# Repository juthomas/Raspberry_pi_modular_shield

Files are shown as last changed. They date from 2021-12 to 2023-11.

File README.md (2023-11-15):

# Raspberry Pi hat for modular synthesizer input

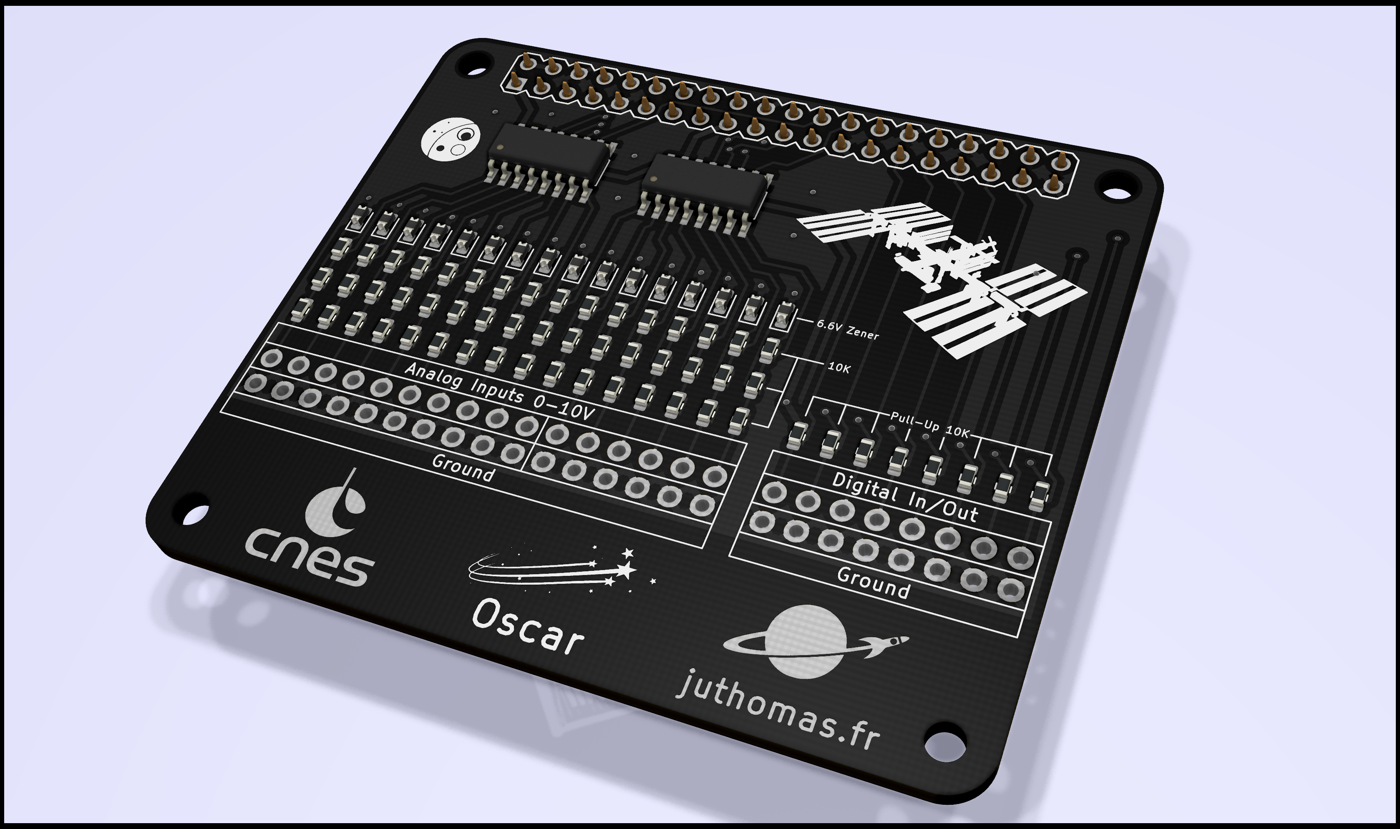
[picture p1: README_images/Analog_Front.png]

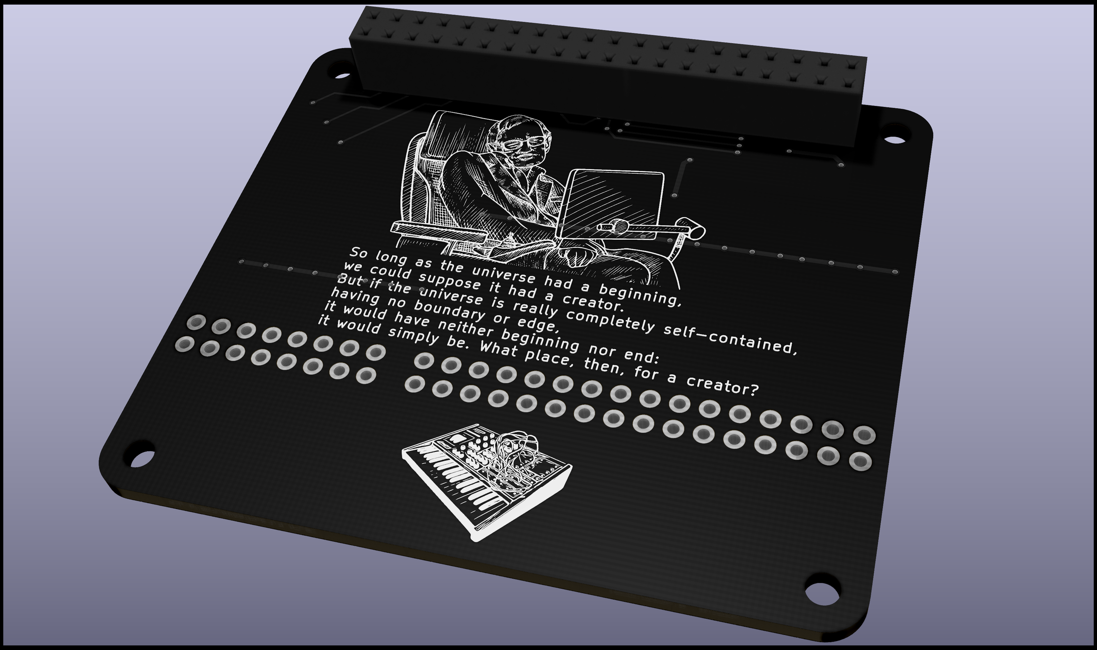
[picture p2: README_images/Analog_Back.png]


## Schematics

- [Link to pdf](https://github.com/juthomas/Raspberry_pi_modular_shield/blob/master/Schematics%20PDF/Modular_Shield.pdf)

## Bill Of Materials

- [Link to IBOM](https://juthomas.github.io/Raspberry_pi_modular_shield/)

## Components

- [10K Resistors](https://www.lcsc.com/product-detail/Chip-Resistor-Surface-Mount_UNI-ROYAL-Uniroyal-Elec-0603WAF1002T5E_C25804.html) C25804

- [Zener Diodes](https://www.lcsc.com/product-detail/Zener-Diodes_onsemi-SZMM5Z6V8T1G_C894569.html) C894569

- [MCP3008](https://www.lcsc.com/product-detail/Analog-To-Digital-Converters-ADCs_Microchip-Tech-MCP3008-I-SL_C1520159.html) C1520159

## Install dependency for C coding

[spidev-lib](https://github.com/juthomas/spidev-lib)

dont forget to add the `-lspidev-lib` flag when compiling

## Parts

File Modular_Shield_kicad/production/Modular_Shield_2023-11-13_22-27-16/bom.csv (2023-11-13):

Designator | Footprint | Quantity | Value | LCSC Part #
D1, D10, D11, D12, D13, D14, D15, D16, D2, D3, D4, D5, D6, D7, D8, D9 | 0603 | 16 | D_Zener 6.6V | C894569
R1, R10, R11, R12, R13, R14, R15, R16, R17, R18, R19, R2, R20, R21, R22, R23, R24, R25, R26, R27, R28, R29, R3, R30, R31, R32, R33, R34, R35, R36, R37, R38, R39, R4, R40, R41, R42, R43, R44, R45, R46, R47, R48, R49, R5, R50, R51, R52, R53, R54, R55, R56, R6, R7, R8, R9 | 0603 | 56 | 10K | C25804
U1, U3 | MCP3008 SOIC16 | 2 | MCP3008 | C1520159

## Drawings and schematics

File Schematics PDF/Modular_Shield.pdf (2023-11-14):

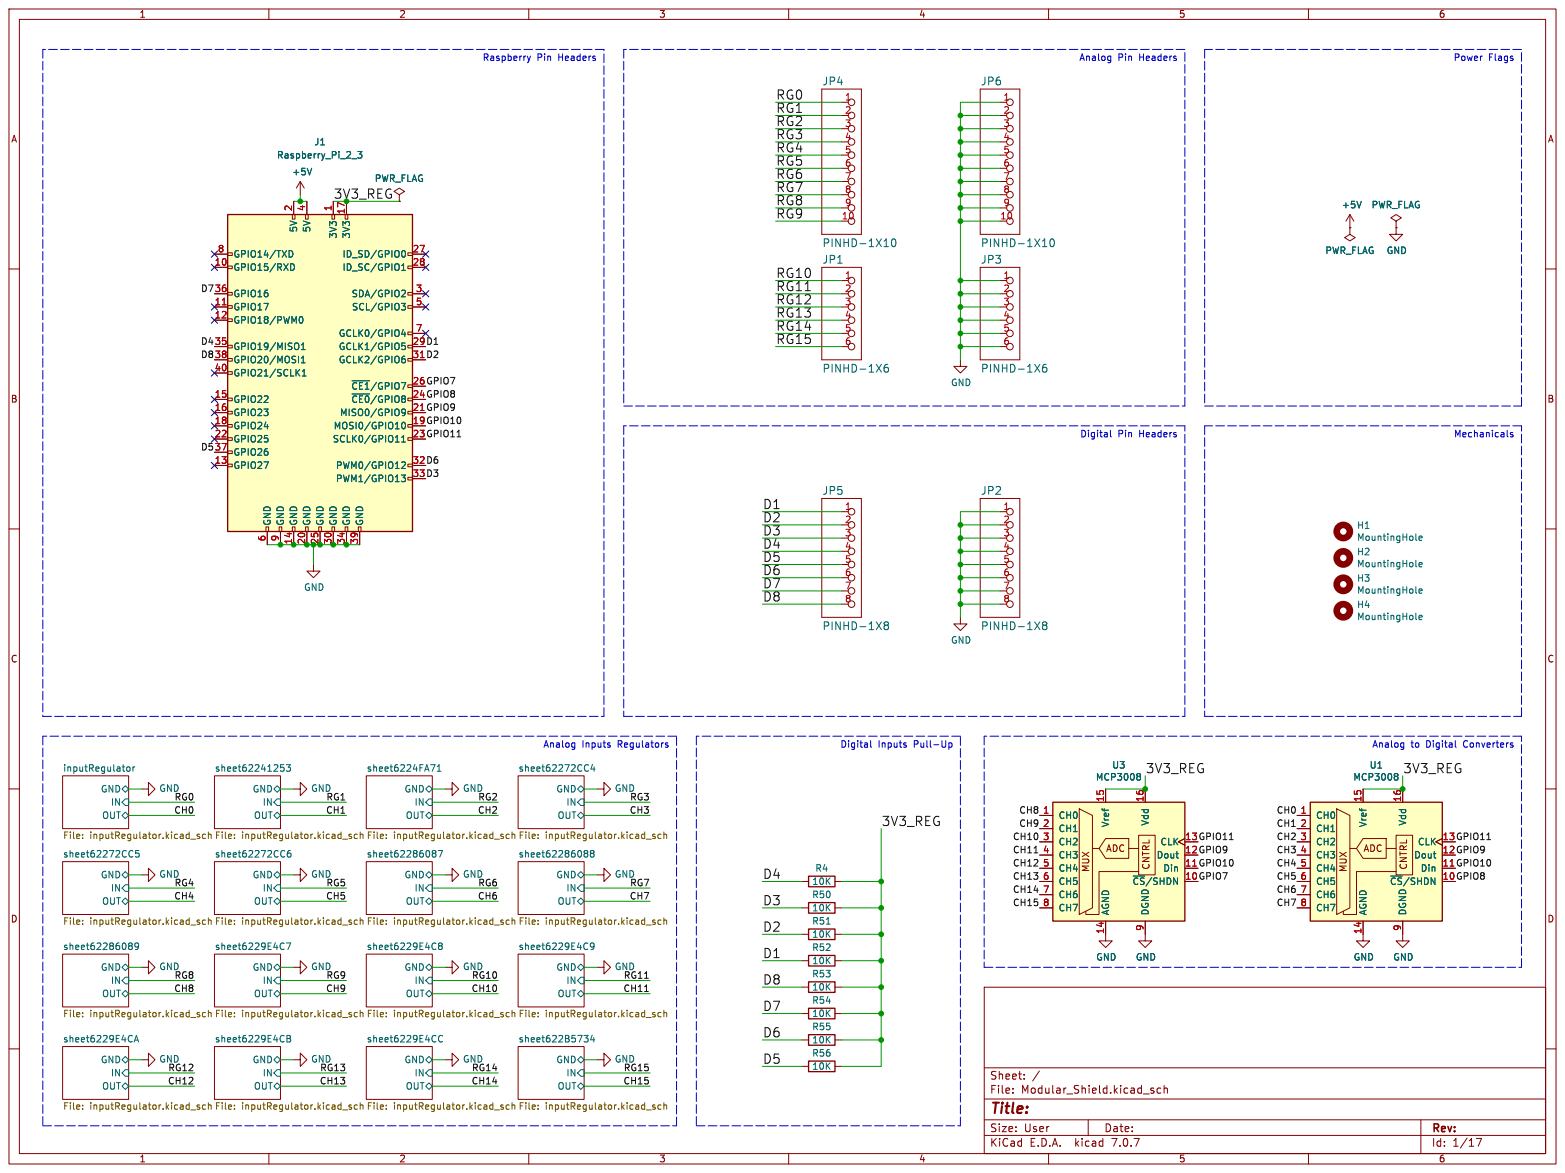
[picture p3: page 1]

9 U3 MCP3008 H1 MountingHole H3 MountingHole H4 MountingHole H2 MountingHole

Digital Inputs Pull-Up

9 U1 MCP3008 GND GND GND GND

9 GND GND GND GND

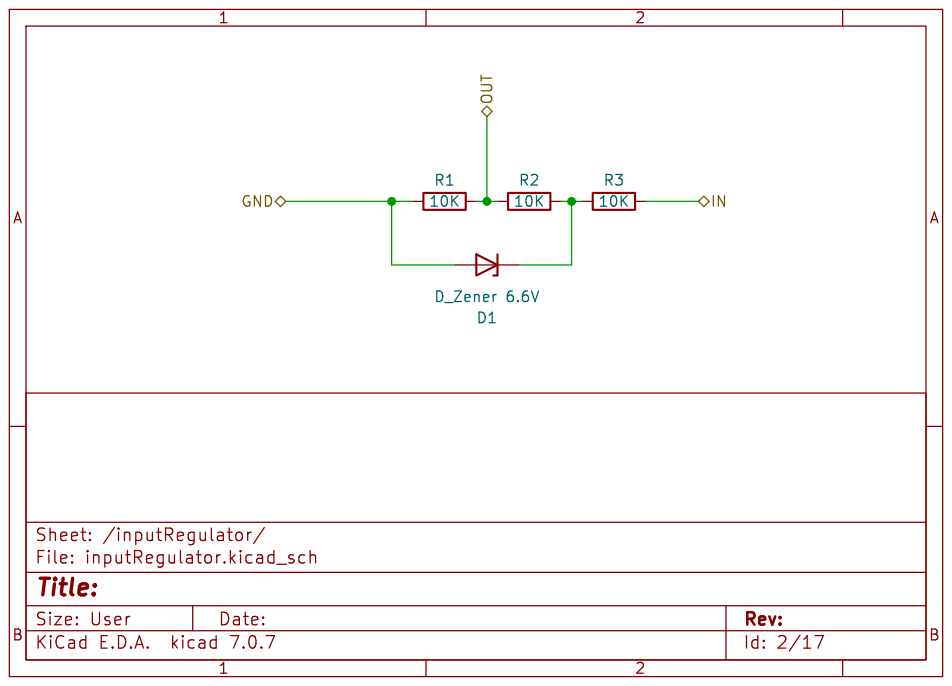
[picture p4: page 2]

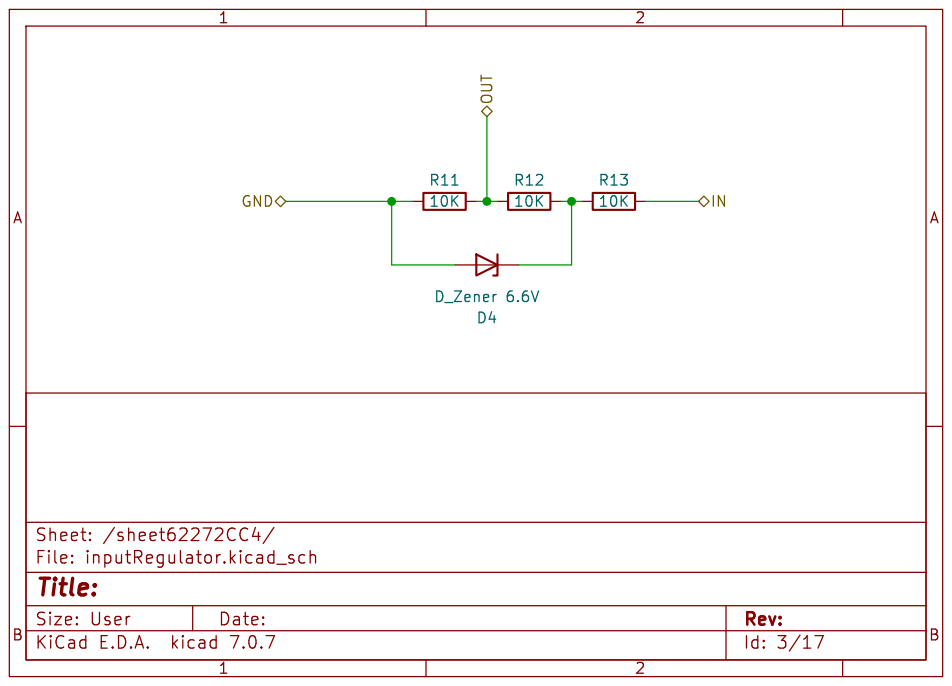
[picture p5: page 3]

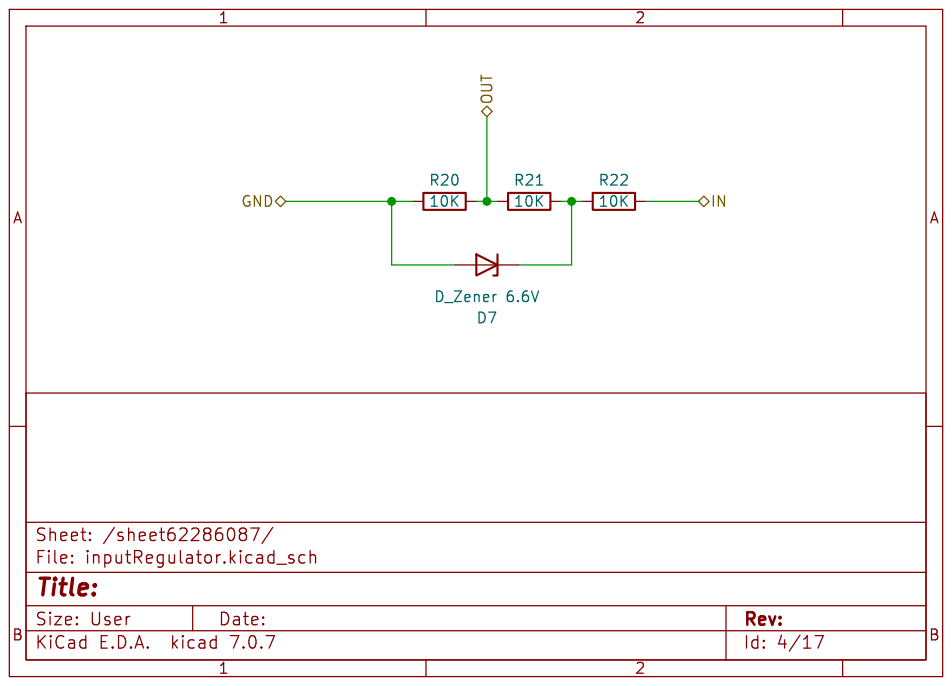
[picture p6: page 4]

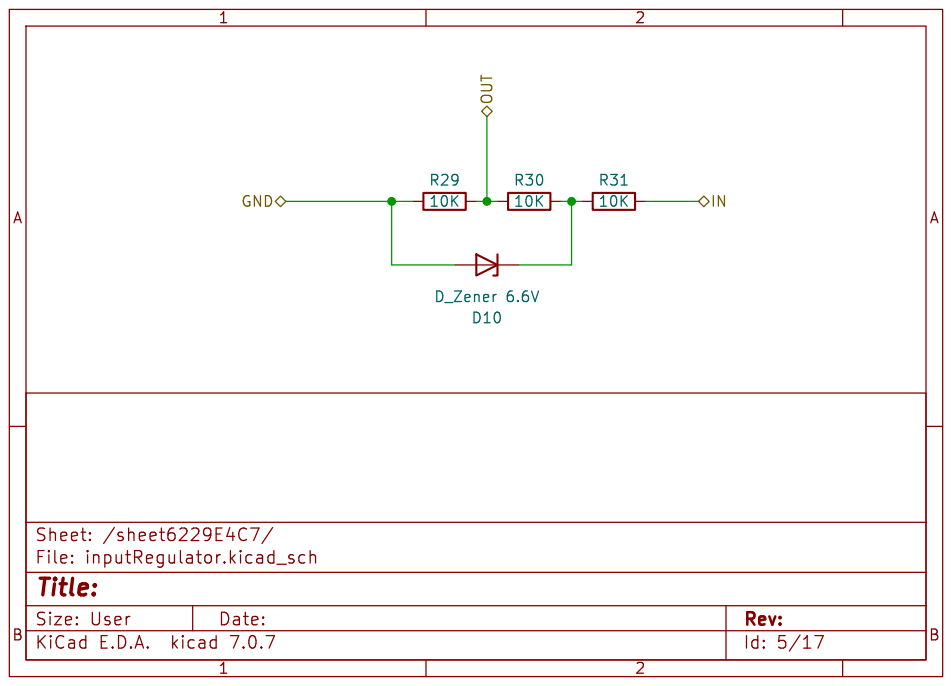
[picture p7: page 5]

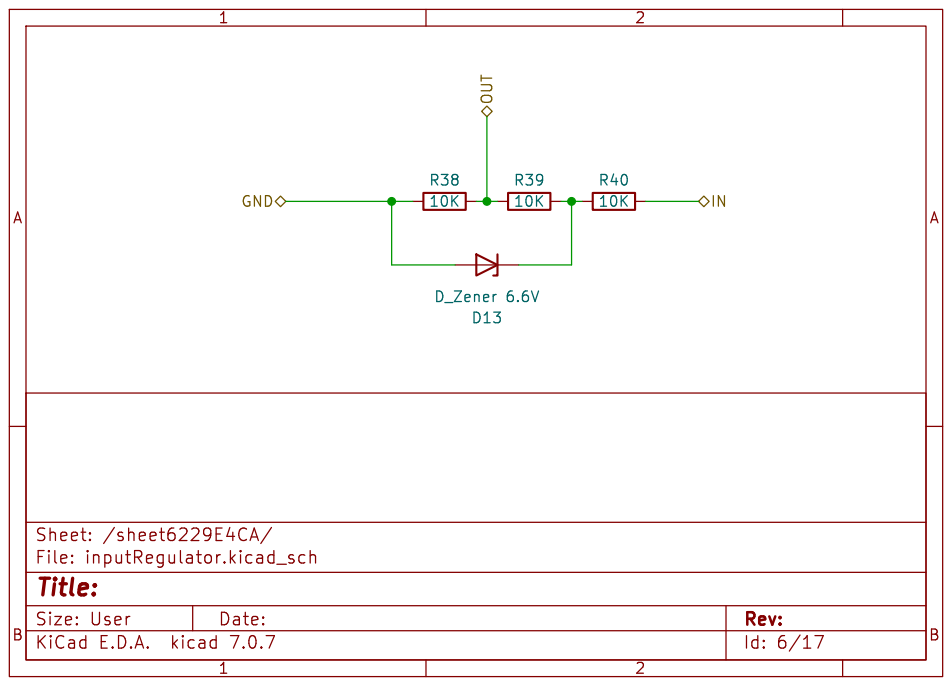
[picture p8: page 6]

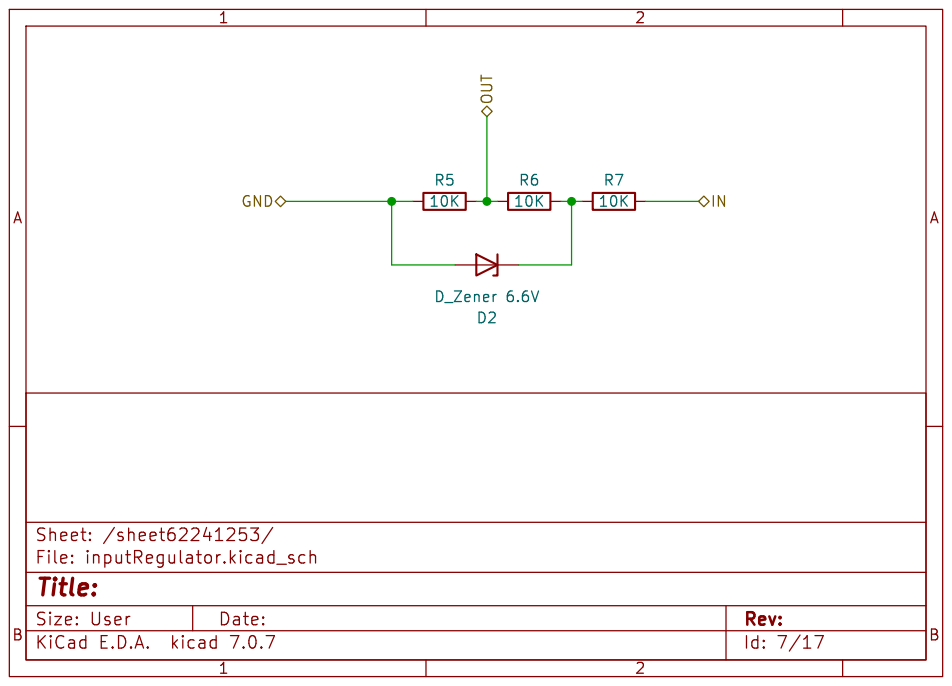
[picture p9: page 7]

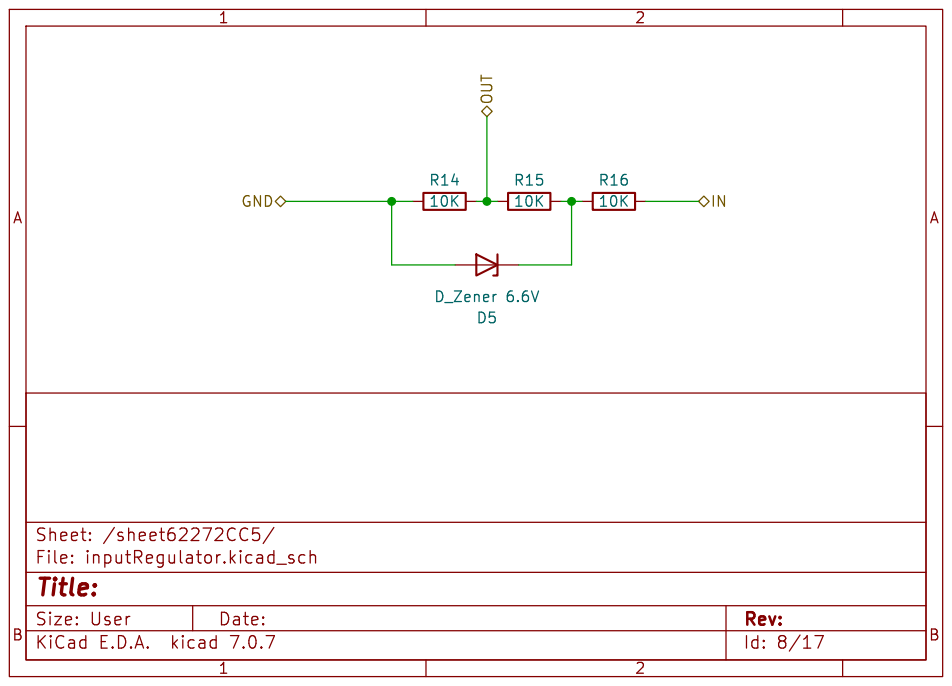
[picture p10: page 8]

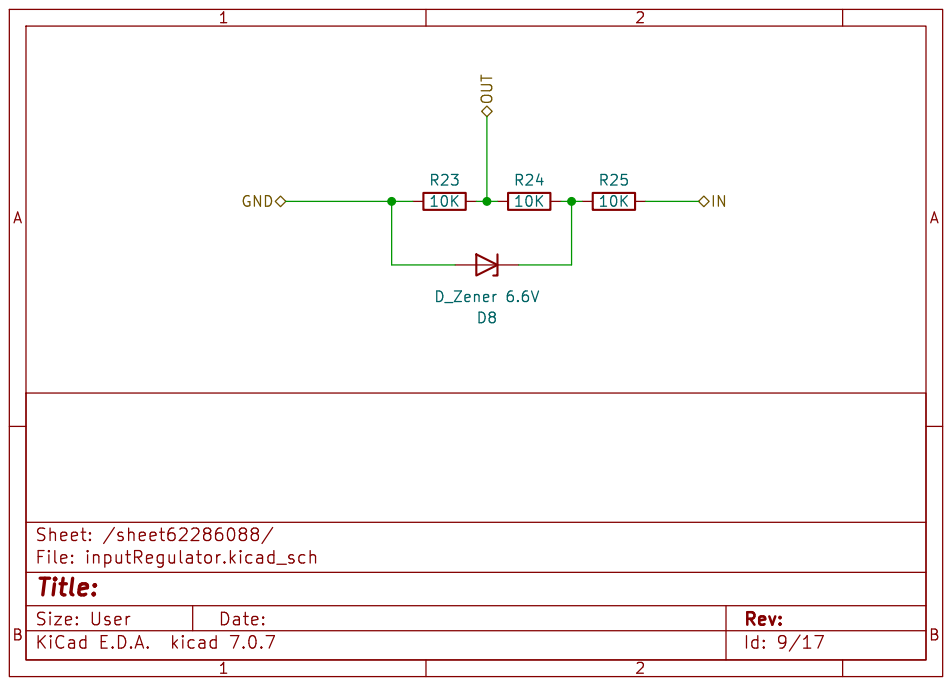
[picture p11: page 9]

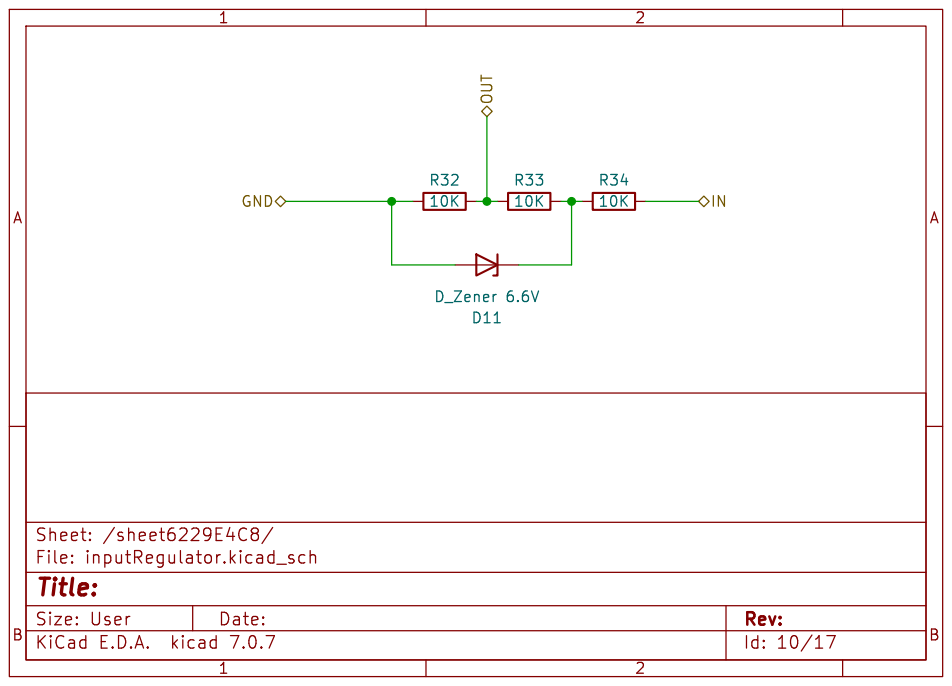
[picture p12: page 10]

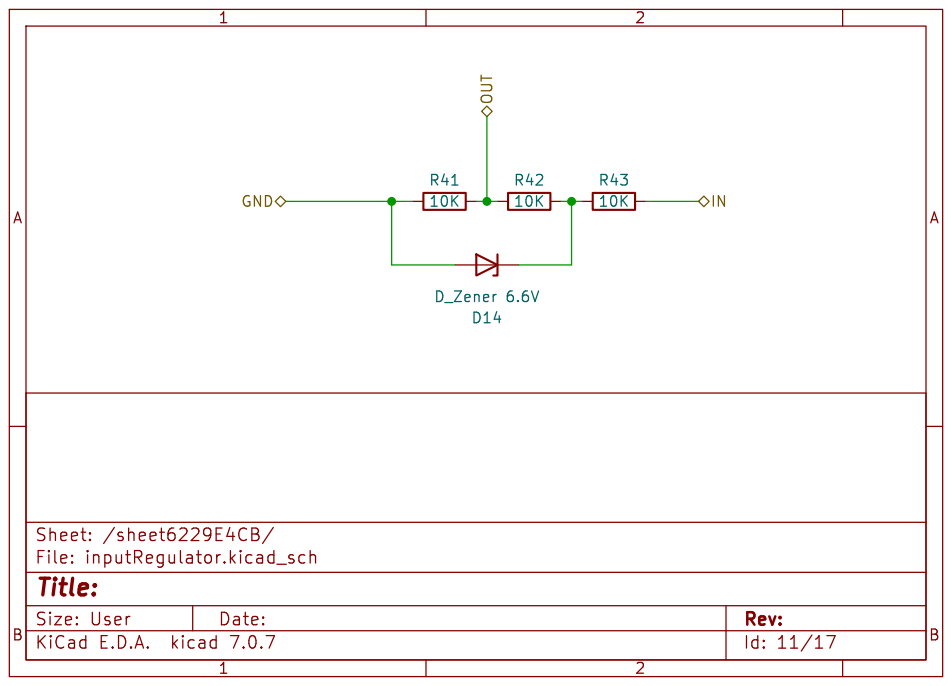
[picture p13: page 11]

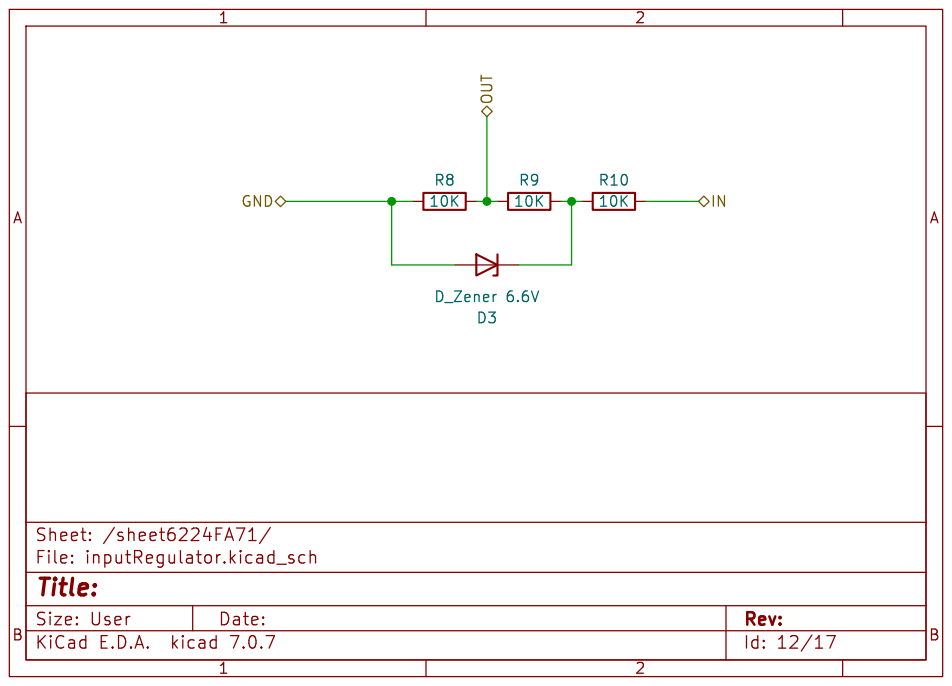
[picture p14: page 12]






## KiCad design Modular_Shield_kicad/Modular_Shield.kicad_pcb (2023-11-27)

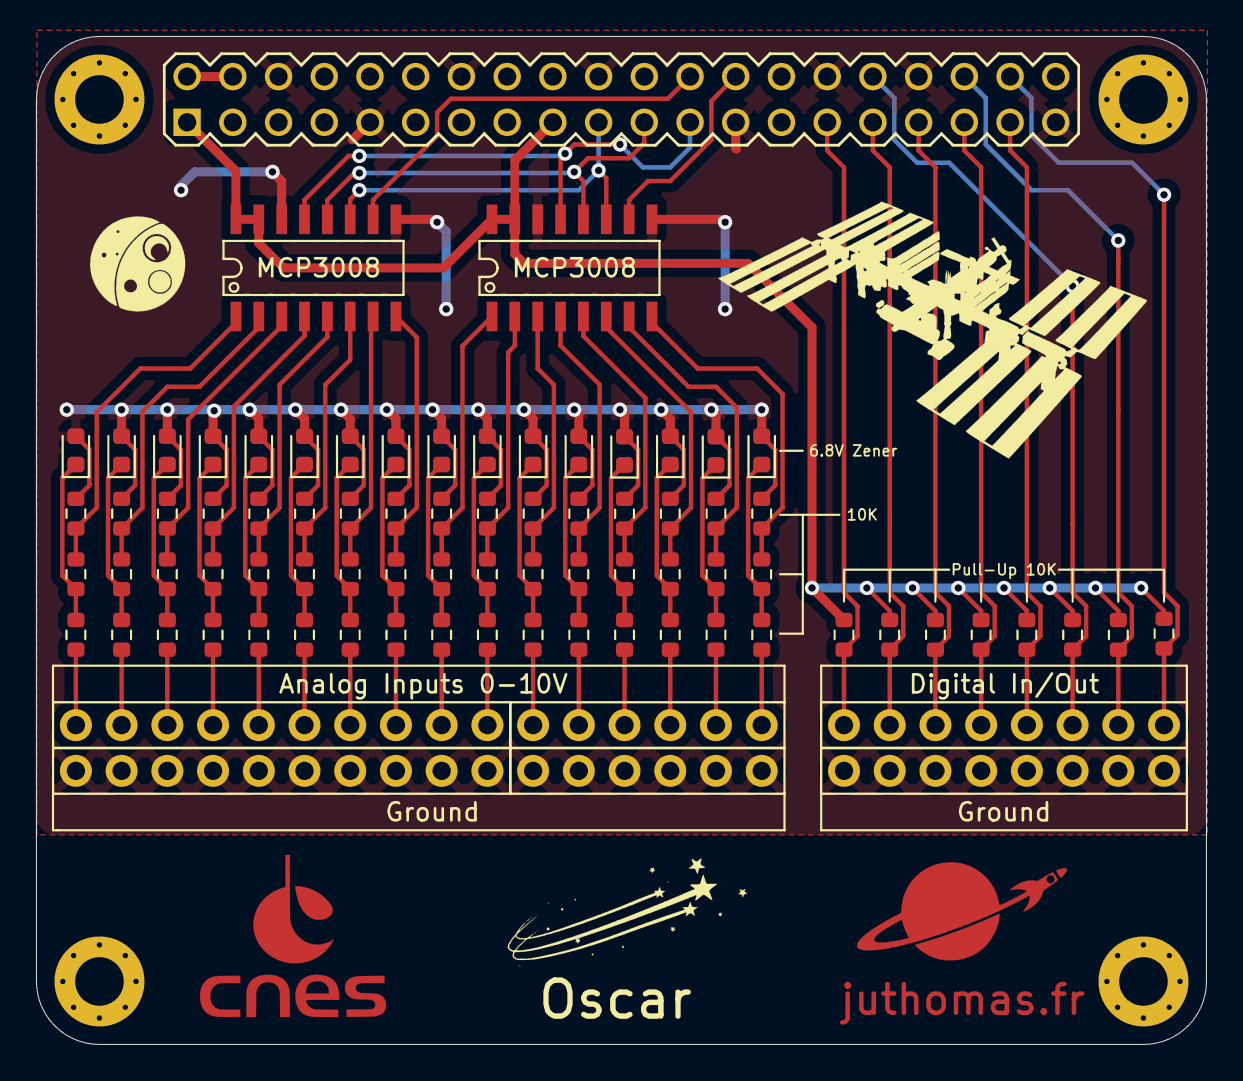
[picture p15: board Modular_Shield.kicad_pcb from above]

Board: 2 copper layers, 65.0 x 56.0 mm, 85 parts (0 on the bottom side), 64 nets.

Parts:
D1, D2, D3, D4, D5, D6, D7, D8, D9, D10, D11, D12, D13, D14, D15, D16: D_Zener 6.6V; D_0603_1608Metric
H1, H2, H3, H4: MountingHole; MountingHole_2.7mm_M2.5
J1: Raspberry_Pi_2_3; PIN_20X2
JP1, JP3: PINHD-1X6; 1X06-BIG
JP2, JP5: PINHD-1X8; 1X08-BIG
JP4, JP6: PINHD-1X10; 1X10-BIG
R1, R2, R3, R4, R5, R6, R7, R8, R9, R10, R11, R12, R13, R14, R15, R16, R17, R18, R19, R20, R21, R22, R23, R24, R25, R26, R27, R28, R29, R30, R31, R32, R33, R34, R35, R36, R37, R38, R39, R40, R41, R42, R43, R44, R45, R46, R47, R48, R49, R50, R51, R52, R53, R54, R55, R56: 10K; R_0603_1608Metric
U1, U3: MCP3008; MCP3008 SOIC16

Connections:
+5V: J1.2 (5V), J1.4 (5V)
/3V3_REG: J1.1 (3V3), J1.17 (3V3), R4.2, R50.2, R51.2, R52.2, R53.2, R54.2, R55.2, R56.2, U1.15 (Vref), U1.16 (Vdd), U3.15 (Vref), U3.16 (Vdd)
/CH0: R1.1, R2.2, U1.1 (CH0)
/CH1: R5.1, R6.2, U1.2 (CH1)
/CH2: R8.1, R9.2, U1.3 (CH2)
/CH3: R11.1, R12.2, U1.4 (CH3)
/CH4: R14.1, R15.2, U1.5 (CH4)
/CH5: R17.1, R18.2, U1.6 (CH5)
/CH6: R20.1, R21.2, U1.7 (CH6)
/CH7: R23.1, R24.2, U1.8 (CH7)
/CH8: R26.1, R27.2, U3.1 (CH0)
/CH9: R29.1, R30.2, U3.2 (CH1)
/CH10: R32.1, R33.2, U3.3 (CH2)
/CH11: R35.1, R36.2, U3.4 (CH3)
/CH12: R38.1, R39.2, U3.5 (CH4)
/CH13: R41.1, R42.2, U3.6 (CH5)
/CH14: R44.1, R45.2, U3.7 (CH6)
/CH15: R47.1, R48.2, U3.8 (CH7)
/D1: J1.29 (GCLK1/GPIO5), JP5.1, R52.1
/D2: J1.31 (GCLK2/GPIO6), JP5.2, R51.1
/D3: J1.33 (PWM1/GPIO13), JP5.3, R50.1
/D4: J1.35 (GPIO19/MISO1), JP5.4, R4.1
/D5: J1.37 (GPIO26), JP5.5, R56.1
/D6: J1.32 (PWM0/GPIO12), JP5.6, R55.1
/D7: J1.36 (GPIO16), JP5.7, R54.1
/D8: J1.38 (GPIO20/MOSI1), JP5.8, R53.1
/GPIO7: J1.26 (~CE1/GPIO7), U3.10 (~CS/SHDN)
/GPIO8: J1.24 (~CE0/GPIO8), U1.10 (~CS/SHDN)
/GPIO9: J1.21 (MISO0/GPIO9), U1.12 (Dout), U3.12 (Dout)
/GPIO10: J1.19 (MOSI0/GPIO10), U1.11 (Din), U3.11 (Din)
/GPIO11: J1.23 (SCLK0/GPIO11), U1.13 (CLK), U3.13 (CLK)
/RG0: JP4.1, R3.1
/RG1: JP4.2, R7.1
/RG2: JP4.3, R10.1
/RG3: JP4.4, R13.1
/RG4: JP4.5, R16.1
/RG5: JP4.6, R19.1
/RG6: JP4.7, R22.1
/RG7: JP4.8, R25.1
/RG8: JP4.9, R28.1
/RG9: JP4.10, R31.1
/RG10: JP1.1, R34.1
/RG11: JP1.2, R37.1
/RG12: JP1.3, R40.1
/RG13: JP1.4, R43.1
/RG14: JP1.5, R46.1
/RG15: JP1.6, R49.1
GND: D1.2 (A), D2.2 (A), D3.2 (A), D4.2 (A), D5.2 (A), D6.2 (A), D7.2 (A), D8.2 (A), D9.2 (A), D10.2 (A), D11.2 (A), D12.2 (A), D13.2 (A), D14.2 (A), D15.2 (A), D16.2 (A), J1.6 (GND), J1.9 (GND), J1.14 (GND), J1.20 (GND), J1.25 (GND), J1.30 (GND), J1.34 (GND), J1.39 (GND), JP2.1, JP2.2, JP2.3, JP2.4, JP2.5, JP2.6, JP2.7, JP2.8, JP3.1, JP3.2, JP3.3, JP3.4, JP3.5, JP3.6, JP6.1, JP6.2, JP6.3, JP6.4, JP6.5, JP6.6, JP6.7, JP6.8, JP6.9, JP6.10, R1.2, R5.2, R8.2, R11.2, R14.2, R17.2, R20.2, R23.2, R26.2, R29.2, R32.2, R35.2, R38.2, R41.2, R44.2, R47.2, U1.9 (DGND), U1.14 (AGND), U3.9 (DGND), U3.14 (AGND)
unnamed: D1.1 (K), R2.1, R3.2
unnamed: D2.1 (K), R6.1, R7.2
unnamed: D3.1 (K), R9.1, R10.2
unnamed: D4.1 (K), R12.1, R13.2
unnamed: D5.1 (K), R15.1, R16.2
unnamed: D6.1 (K), R18.1, R19.2
unnamed: D7.1 (K), R21.1, R22.2
unnamed: D8.1 (K), R24.1, R25.2
unnamed: D9.1 (K), R27.1, R28.2
unnamed: D10.1 (K), R30.1, R31.2
unnamed: D11.1 (K), R33.1, R34.2
unnamed: D12.1 (K), R36.1, R37.2
unnamed: D13.1 (K), R39.1, R40.2
unnamed: D14.1 (K), R42.1, R43.2
unnamed: D15.1 (K), R45.1, R46.2
unnamed: D16.1 (K), R48.1, R49.2

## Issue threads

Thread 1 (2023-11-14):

IN/OUT Board Version

juthomas, 2023-11-14:
### Develop a Version with 10V Output
- Utilize LM324 as the Operational Amplifier
- Employ MCP4728 for DAC functionality

juthomas, 2023-11-26:
New repo added : [juthomas/Raspberry_pi_modular_hat_in_out](https://github.com/juthomas/Raspberry_pi_modular_hat_in_out)

Closed 2023-11-26.

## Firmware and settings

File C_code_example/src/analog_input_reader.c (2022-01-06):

#include <stdio.h>
#include <stdlib.h>
#include <string.h>
#include <spidev_lib.h>
#include <unistd.h>

float get_voltage_value(uint8_t channel)
{
	spi_config_t	spi_config;
	uint8_t			tx_buffer[3] = {0};
	uint8_t 		rx_buffer[3] = {0};
	int				spifd;
	float			voltage_value;

	spi_config.mode=0;
	spi_config.speed=1000000;
	spi_config.delay=0;
	spi_config.bits_per_word=8;

	spifd=spi_open(channel < 8 ? "/dev/spidev0.0" : "/dev/spidev0.1",spi_config);
	if (spifd < 0)
	{
		printf("make sure that \"/dev/spidev0.0\" and \"/dev/spidev0.1\" are available\n");
		return (-1);
	}
	tx_buffer[0] = 1;
	tx_buffer[1] = ((8 + channel - (channel < 8 ? 0 : 8)) << 4);
	tx_buffer[2] = 0;
	spi_xfer(spifd,tx_buffer,3,rx_buffer,3);
	voltage_value = (float)(((rx_buffer[1] & 3) << 8) + rx_buffer[2]) / 1023.0 * 9.9;
	spi_close(spifd); 
	return (voltage_value);
}

void main( void)
{
	for (;;)
	{
		for (int i = 0; i < 16; i++)
		{
			printf("%.2f ", get_voltage_value(i));
		}
		printf("\n");
		sleep(1);
	}
	return (0);
}

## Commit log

2021-12-10 [INIT] Kicad fonctionnal
    [Raspberry_modular.kicad_pcb, Raspberry_modular.sch, inputRegulator.sch]
2021-12-12 [ADD] Gerber files
    [Raspberry_modular-B_Mask.gbr, Raspberry_modular-B_Paste.gbr, Raspberry_modular-B_SilkS.gbr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]
2022-01-06 [ADD] Error message for open fd failed
    [analog_input_reader.c]
2023-11-12 [ERC] Fix problems by creating new libs
    [Raspberry_modular.kicad_pcb, Raspberry_modular.kicad_sch, inputRegulator.kicad_sch]
2023-11-12 [UDPT] All symbols are now in lib
    [Raspberry_modular.kicad_sch, inputRegulator.kicad_sch]
2023-11-12 [UDPT] Inputs on schematics
    [Raspberry_modular.kicad_pcb, Raspberry_modular.kicad_sch, inputRegulator.kicad_sch]
2023-11-12 [FIX] Connection problems
    [Raspberry_modular.kicad_sch]
2023-11-12 [UDPT] Shematics
    [Raspberry_modular.kicad_sch, inputRegulator.kicad_sch]
2023-11-12 [FIX] Missing annotations
    [Raspberry_modular.kicad_sch]
2023-11-13 [UDPT] Electricals footprints
    [Raspberry_modular.kicad_pcb, Raspberry_modular.kicad_sch, inputRegulator.kicad_sch]
2023-11-13 [DRC] Problems fixed
    [Raspberry_modular.kicad_pcb]
2023-11-13 [UDPT] Filled Zones
    [Raspberry_modular.kicad_pcb]
2023-11-13 [ADD] 2x20 Socket 3d
    [Raspberry_modular.kicad_pcb]
2023-11-13 [ADD] Bom
    [Raspberry_modular.kicad_pcb, Raspberry_modular.kicad_sch, bom.csv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]
2023-11-13 [FIX] Some productions problems
    [Raspberry_modular.kicad_pcb, Raspberry_modular.kicad_sch, bom.csv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]
2023-11-13 [FIX] Production build
    [Raspberry_modular.kicad_pcb, Raspberry_modular.kicad_sch, bom.csv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]
2023-11-13 [ADD] Production build with updated Silk
    [Raspberry_modular.kicad_pcb, bom.csv, designators.csv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]
2023-11-13 [ADD] Schematics PDFs
2023-11-13 [UDPT] Kicad Project name
    [Modular_Shield.kicad_pcb, Modular_Shield.kicad_sch, Modular_Shield.sch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]
2023-11-13 [CLEAN] Removed Useless files/folders
    [Modular_Shield.kicad_pcb, bom.csv, designators.csv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]
2023-11-13 [FIX] Build production
    [Modular_Shield.kicad_pcb, bom.csv, designators.csv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]
2023-11-13 [UDPT] Schematics PDFs
2023-11-13 [FIX] Missing Text On IBOM
    [Modular_Shield.kicad_pcb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]
2023-11-27 [UDPT] Mounting Holes Upgraded
    [Modular_Shield.kicad_pcb]
